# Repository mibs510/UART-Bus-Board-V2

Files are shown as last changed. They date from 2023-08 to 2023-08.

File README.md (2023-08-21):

# UART Bus Board V2
  A UART bus to configure MKS SERVO42C closed looped stepper drivers on my 5' x 6.5' laser CNC

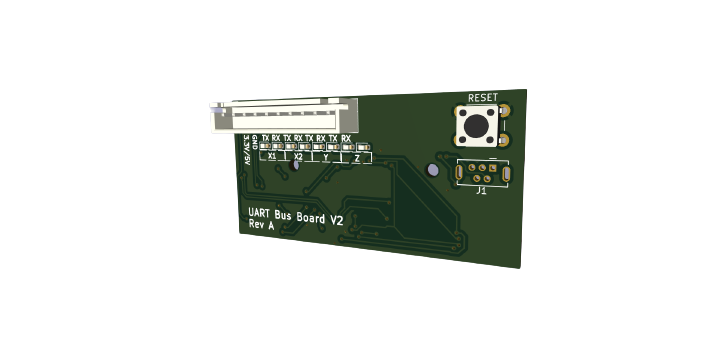
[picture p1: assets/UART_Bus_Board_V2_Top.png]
Top view of UART Bus Board V2

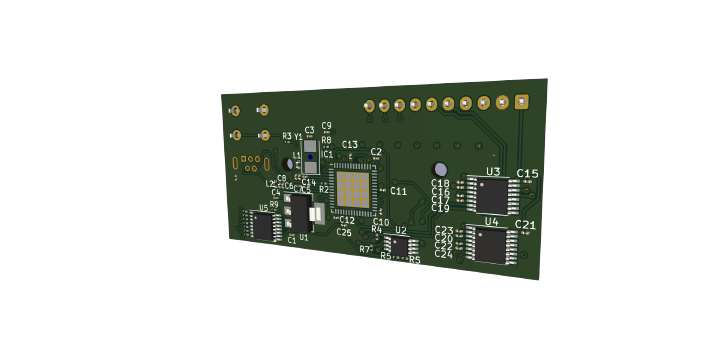
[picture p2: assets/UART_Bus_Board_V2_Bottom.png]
Bottom view of UART Bus Board V2


# Block Diagram
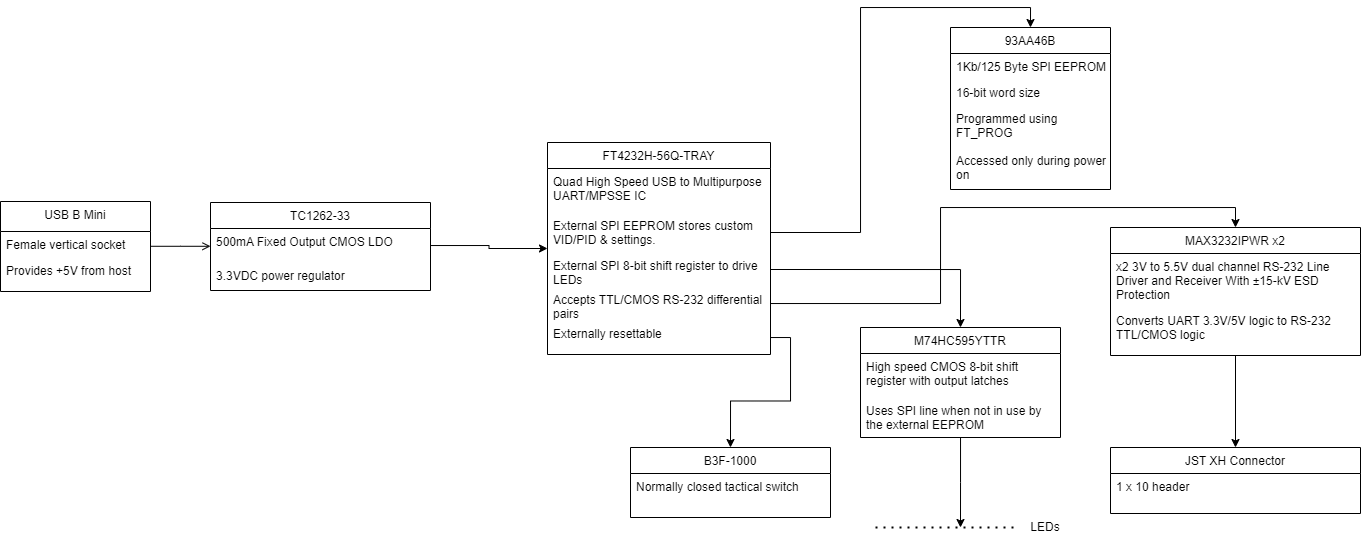
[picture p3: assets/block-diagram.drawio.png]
UART Bus Board V2 Block Diagram


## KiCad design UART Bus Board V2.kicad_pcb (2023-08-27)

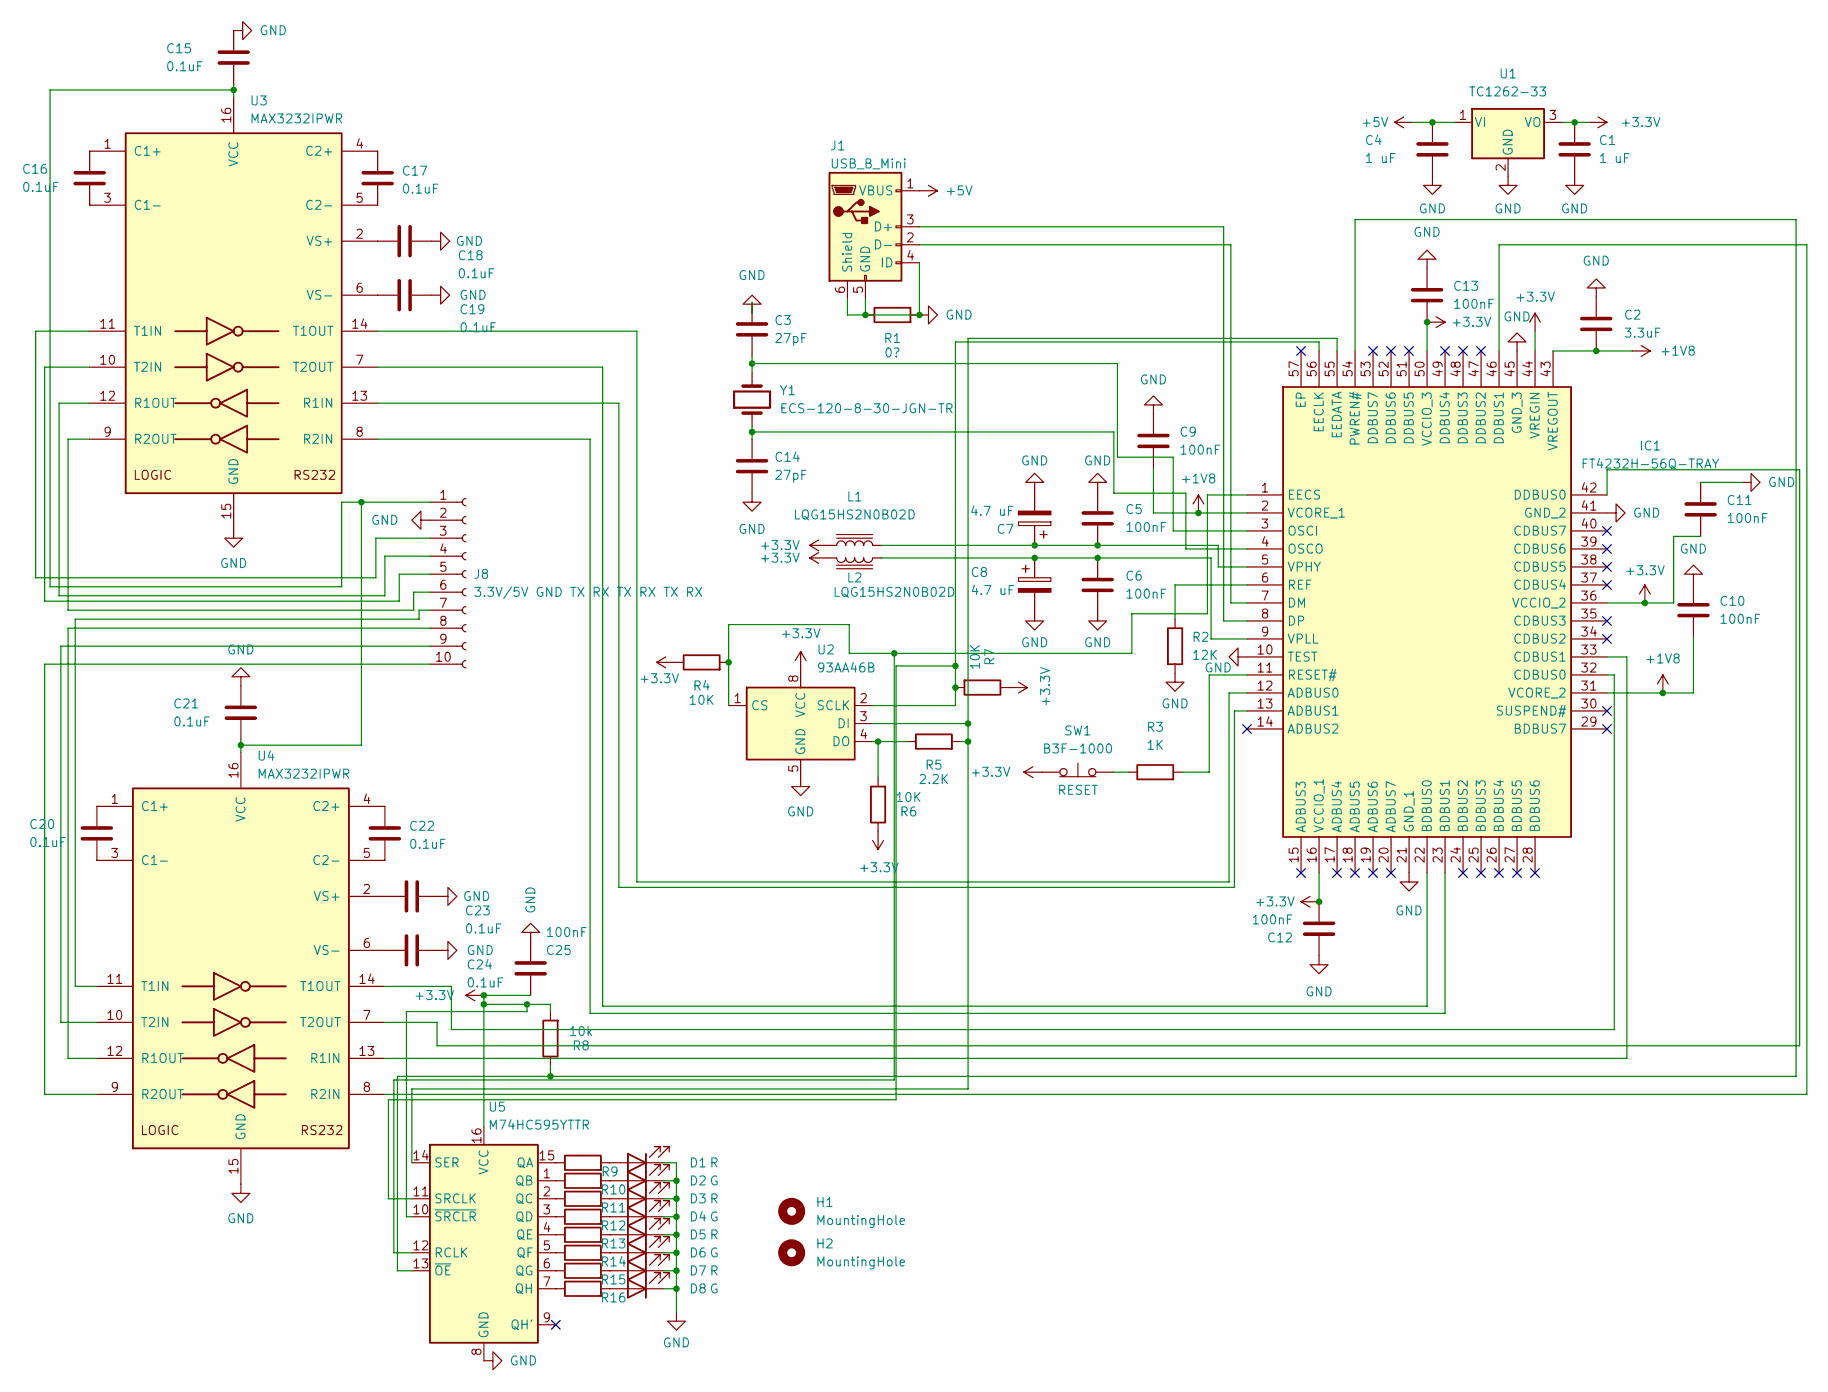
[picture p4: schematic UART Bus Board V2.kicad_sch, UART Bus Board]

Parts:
C1, C4: 1 uF; C_0201_0603Metric
C2: 3.3uF; C_0201_0603Metric
C3, C14: 27pF; C_0201_0603Metric
C5, C6, C9, C10, C11, C12, C13, C25: 100nF; C_0201_0603Metric
C7, C8: 4.7 uF; C_0201_0603Metric
C15, C16, C17, C18, C19, C20, C21, C22, C23, C24: 0.1uF; C_0201_0603Metric
D1, D3, D5, D7: R; LED_0603_1608Metric
D2, D4, D6, D8: G; LED_0603_1608Metric
H1, H2: MountingHole; MountingHole_2.2mm_M2
IC1: FT4232H-56Q-TRAY; QFN-56-1EP_8x8mm_P0.5mm_EP5.9x5.9mm; Mouser Part Number 895-FT4232H-56Q-TRAY
J1: USB_B_Mini; USB_Mini-B_Tensility_54-00023_Vertical
J8: 3.3V/5V GND TX RX TX RX TX RX; JST_XH_B10B-XH-A_1x10_P2.50mm_Vertical
L1, L2: LQG15HS2N0B02D; L_0402_1005Metric
R1: 0?; R_0201_0603Metric
R2: 12K; R_0201_0603Metric
R3: 1K; R_0201_0603Metric
R4, R6, R7: 10K; R_0201_0603Metric
R5: 2.2K; R_0201_0603Metric
R8: 10k; R_0201_0603Metric
R9, R10, R11, R12, R13, R14, R15, R16: 330R; R_0201_0603Metric
SW1: B3F-1000; SW_PUSH_6mm
U1: TC1262-33; SOT-223-3_TabPin2
U2: 93AA46B; MSOP-8_3x3mm_P0.65mm
U3, U4: MAX3232IPWR; TSSOP-16_4.4x5mm_P0.65mm
U5: M74HC595YTTR; TSSOP-16_4.4x5mm_P0.65mm
Y1: ECS-120-8-30-JGN-TR; Crystal_SMD_5032-2Pin_5.0x3.2mm

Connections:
+3.3V: C1.1, C11.2, C12.2, C13.2, C25.2, IC1.16 (VCCIO_1), IC1.36 (VCCIO_2), IC1.44 (VREGIN), IC1.50 (VCCIO_3), L1.1, L2.2, R4.1, R6.1, R7.1, R8.2, SW1.1 (A), U1.3 (VO), U2.8 (VCC), U5.10 (~SRCLR), U5.16 (VCC)
+5V: C4.1, J1.1 (VBUS), U1.1 (VI)
GND: C1.2, C2.1, C3.1, C4.2, C5.1, C6.2, C7.2, C8.2, C9.1, C10.1, C11.1, C12.1, C13.1, C14.2, C15.1, C18.1, C19.1, C21.1, C23.1, C24.1, C25.1, D1.1 (K), D2.1 (K), D3.1 (K), D4.1 (K), D5.1 (K), D6.1 (K), D7.1 (K), D8.1 (K), IC1.10 (TEST), IC1.21 (GND_1), IC1.41 (GND_2), IC1.45 (GND_3), J1.4 (ID), J1.5 (GND), J1.6 (Shield), J8.2, R1.1, R1.2, R2.2, U1.2 (GND), U2.5 (GND), U3.15 (GND), U4.15 (GND), U5.8 (GND)
unnamed: D1.2 (A), R9.2
unnamed: D2.2 (A), R10.2
unnamed: D3.2 (A), R11.2
unnamed: D4.2 (A), R12.2
unnamed: D5.2 (A), R13.2
unnamed: D6.2 (A), R14.2
unnamed: D7.2 (A), R15.2
unnamed: D8.2 (A), R16.2
unnamed: IC1.12 (ADBUS0), U3.14 (T1OUT)
unnamed: IC1.13 (ADBUS1), U3.13 (R1IN)
unnamed: IC1.22 (BDBUS0), U3.7 (T2OUT)
unnamed: IC1.23 (BDBUS1), U3.8 (R2IN)
unnamed: IC1.32 (CDBUS0), U4.14 (T1OUT)
unnamed: IC1.33 (CDBUS1), U4.13 (R1IN)
unnamed: IC1.42 (DDBUS0), U4.7 (T2OUT)
unnamed: IC1.46 (DDBUS1), U4.8 (R2IN)
unnamed: IC1.7 (DM), J1.2 (D-)
unnamed: IC1.8 (DP), J1.3 (D+)
unnamed: IC1.56 (EECLK), R7.2, U2.2 (SCLK), U5.11 (SRCLK)
unnamed: IC1.1 (EECS), R4.2, U2.1 (CS), U5.12 (RCLK)
unnamed: IC1.55 (EEDATA), R5.2, U2.3 (DI), U5.14 (SER)
unnamed: C3.2, IC1.3 (OSCI), Y1.2
unnamed: C14.1, IC1.4 (OSCO), Y1.1
unnamed: IC1.54 (PWREN#), R8.1, U5.13 (~OE)
unnamed: IC1.6 (REF), R2.1
unnamed: IC1.11 (RESET#), R3.2
unnamed: C5.2, C7.1, IC1.5 (VPHY), L1.2
unnamed: C6.1, C8.1, IC1.9 (VPLL), L2.1
unnamed: C15.2, C21.2, J8.1, U3.16 (VCC), U4.16 (VCC)
unnamed: J8.3, U3.11 (T1IN)
unnamed: J8.4, U3.12 (R1OUT)
unnamed: J8.5, U3.10 (T2IN)
unnamed: J8.6, U3.9 (R2OUT)
unnamed: J8.7, U4.11 (T1IN)
unnamed: J8.8, U4.12 (R1OUT)
unnamed: J8.9, U4.10 (T2IN)
unnamed: J8.10, U4.9 (R2OUT)
unnamed: R3.1, SW1.2 (B)
unnamed: R5.1, R6.2, U2.4 (DO)
unnamed: C16.1, U3.1 (C1+)
unnamed: C16.2, U3.3 (C1-)
unnamed: C17.1, U3.4 (C2+)
unnamed: C17.2, U3.5 (C2-)
unnamed: C18.2, U3.2 (VS+)
unnamed: C19.2, U3.6 (VS-)
unnamed: C20.1, U4.1 (C1+)
unnamed: C20.2, U4.3 (C1-)
unnamed: C22.1, U4.4 (C2+)
unnamed: C22.2, U4.5 (C2-)
unnamed: C23.2, U4.2 (VS+)
unnamed: C24.2, U4.6 (VS-)
unnamed: R9.1, U5.15 (QA)
unnamed: R10.1, U5.1 (QB)
unnamed: R11.1, U5.2 (QC)
unnamed: R12.1, U5.3 (QD)
unnamed: R13.1, U5.4 (QE)
unnamed: R14.1, U5.5 (QF)
unnamed: R15.1, U5.6 (QG)
unnamed: R16.1, U5.7 (QH)

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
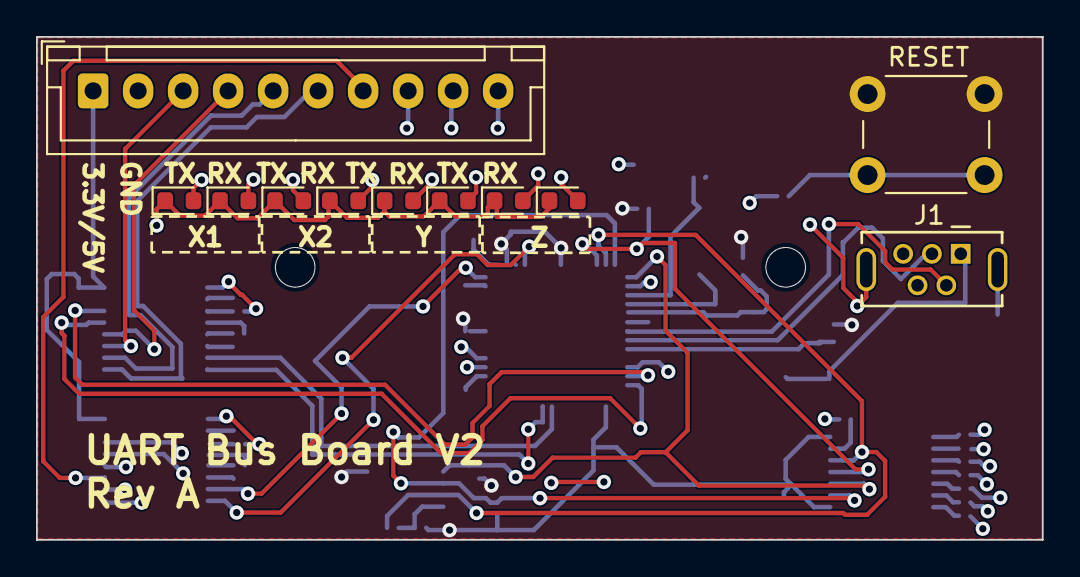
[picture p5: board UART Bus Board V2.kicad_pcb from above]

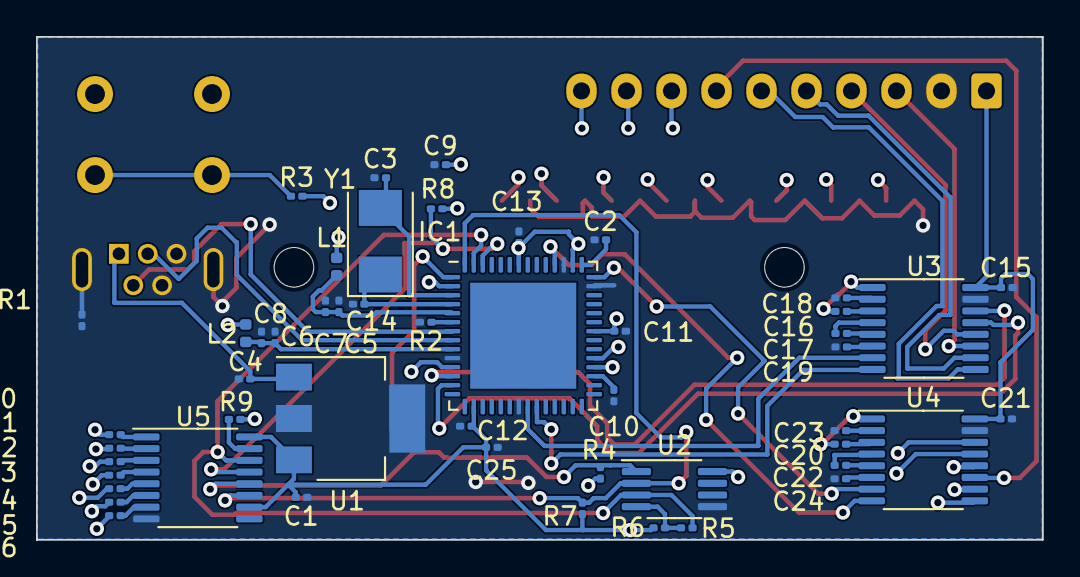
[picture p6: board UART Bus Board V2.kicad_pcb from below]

Board: 4 copper layers, 55.9 x 27.9 mm, 63 parts (50 on the bottom side), 65 nets.

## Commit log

2023-08-21 Initial commit. Rev A
    Initial commit! Starting with revision A!
    [UART Bus Board V2.kicad_pcb, UART Bus Board V2.kicad_sch]
2023-08-21 Buried/Blinded Vias
    Unburied vias that didn't need to be buried in the first place.
    [UART Bus Board V2.kicad_pcb]
2023-08-21 Errors & warning
    Fixed a couple of errors and warnings that the DRC reported.
    [UART Bus Board V2.kicad_pcb, UART Bus Board V2.kicad_sch]
2023-08-27 clearances/minimums + burried vias + PCBWay
    Lowered clearances and minimums on the top fill layer
    Removed three buried/hidden vias
    Passing on PCBWay without issues
    [UART Bus Board V2.kicad_pcb, UART Bus Board V2.kicad_sch]
